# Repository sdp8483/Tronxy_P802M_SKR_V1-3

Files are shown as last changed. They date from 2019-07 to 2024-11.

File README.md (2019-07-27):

# Tronxy P802M with BIGTREETECH SKR V1.3 Controller - Marlin 2.0 Firmware Cofiguration Files

Upgrade guide for replacing stock Tronxy P802M controller: [samueldperry.com](https://samueldperry.com/2019/07/21/tronxy-p802m-controller-upgrade-to-32-bits/ "Upgrade Guide")

For stock hardware (other then the controller) use config files in *Stock Hardware* directory.

For 3D Touch Probe (BLTouch Clone)) use config files in *3D Touch* directory.

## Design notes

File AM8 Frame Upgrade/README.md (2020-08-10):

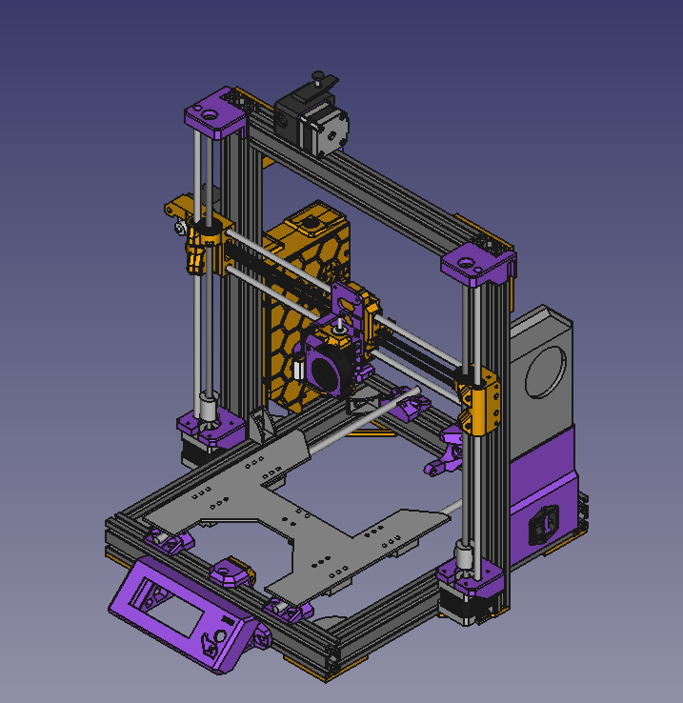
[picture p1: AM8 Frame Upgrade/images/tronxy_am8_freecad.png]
Tronxy AM8 FreeCAD Render


# Frame
[AM8 Frame](https://www.thingiverse.com/thing:2263216): use for aluminum cut dimensions and printed frame support parts.
Follow the [AM8 Build guide](https://www.thingiverse.com/download:3592429) but substitute the modified parts below for the original AM8 printed parts.

# Printed Parts
Parts are borrowed from the sources listed in the [Sources and Inspiration](#sources-and-inspiration) section.
The AM8 2040 extrusion profile is different from the Prusa Bear 2040 extrusion profile so parts that connect to the 2040 profiles have been modified.

Item Number | Item | Quantity | Notes
------------|------|----------|------
1  | [AM8 to corner plate](CAD/stl/2_Top_Corner_Plate.stl) | 2 | from [AM8 Frame](https://www.thingiverse.com/thing:2263216)
2  | [AM8 bottom tee plate](CAD/stl/2_Bottom_Tee_Plate.stl) | 2 | from [AM8 Frame](https://www.thingiverse.com/thing:2263216)
3  | [AM8 bottom corner plate](CAD/stl/4_Bottom_Corner_Plate.stl) | 4 | from [AM8 Frame](https://www.thingiverse.com/thing:2263216)
4  | [left z motor mount](CAD/stl/z_motor_mount_left.stl) | 1 | based on z motor mounts from full Prusa Bear Upgrade
5  | [right z motor mount](CAD/stl/z_motor_mount_right.stl) | 1 | based on z motor mounts from full Prusa Bear Upgrade
6  | [left z stabilizer](CAD/stl/z_stabilizer_left.stl) | 1 | holds z smooth rod and leadscrew, requires 608 bearing
7  | [right z stabilizer](CAD/stl/z_stabilizer_right.stl) | 1 | holds z smooth rod and leadscrew, requires 608 bearing
8  | [x motor mount](CAD/stl/x_end_motor.stl) | 1 | unmodifed from Prusa Bear Upgrade. Print the mk2.5s version if using limit switches. Either if using sensorless homing
9  | [x end idler](CAD/stl/x_end_idler.stl) | 1 | unmodifed from Prusa Bear Upgrade, cut x rods to 405mm long
10 | [x end idler tensioner](CAD/stl/x_end_idler_tensioner.stl) | 1 | unmodifed from Prusa Bear Upgrade.
11 | [y rod holder](CAD/stl/y_rod_holder.stl) | 4 | 
12 | [y motor mount](CAD/stl/y_motor_mount_modified.stl) | 1 | modified prusa bear part to fit extrusion profile
13 | [y idler bottom](CAD/stl/y_idler_bottom_modified.stl) | 1 | modified from Thingiverse thing:[3502543](https://www.thingiverse.com/thing:3502543) to fit extrusion profile
14 | [y idler holder](CAD/stl/y_idler_holder_Bear_RHD.stp) | 1 | unmodified from Thingiverse thing:[3502543](https://www.thingiverse.com/thing:3502543)
15 | [y belt holder](CAD/stl/y_belt_holder.stl) | 1 |
16 | [x carriage back](CAD/stl/x_carriage_back.stl) | 1 | unmodifed from Prusa Bear Upgrade.
17 | [x carriage](CAD/stl/x_carriage.stl) | 1 | unmodifed from Prusa Bear Upgrade.
18 | [hotend mount](CAD/stl/hotend_mount_modified.stl) | 1 | modified from Prusa Bear Upgrade for bowden setup
19 | [extruder cover](CAD/stl/extruder_cover.stl) | 1 | unmodified from Prusa Bear upgrade
20 | [cable guide back A](CAD/stl/cable_guide_back_a.stl) | 1 | unmodified from Prusa Bear upgrade
21 | [cable guide back B](CAD/stl/cable_guide_back_b.stl) | 1 | unmodified from Prusa Bear upgrade
22 | [lcd support a modified](CAD/stl/lcd_support_a_modified.stl) | 1 | modified prusa bear part to fit extrusion profile and for LCD contrast pot
23 | [lcd support b modified](CAD/stl/lcd_support_b_modified.stl) | 1 | modified prusa bear part to fit extrusion profile
24 | [lcd cover](CAD/stl/lcd_cover.stl) | 1 | modified from prusa
25 | [SKR V14 Body](CAD/stl/SKR_V14_Body.stl) | 1 | unmodified from Universal BTT SKR Box
26 | [SKR V14 Cover](CAD/stl/SKR_V14_Cover.stl) | 1 | unmodified from Universal BTT SKR Box
27 | [SKR Bear Long Anchor Modified](CAD/stl/Anchor_SKR_Bear_Long_modified.stl) | 1 | modified version of Universal BTT SKR mount, attaches enclosure to frame
28 | [Bear MK3 Body](CAD/stl/Bear_MK3_Body.stl) | 1 | unmodified from Universal BTT SKR Box
29 | [Bear MK3 Cover](CAD/stl/Bear_MK3_Cover.stl) | 1 | unmodified from Universal BTT SKR Box
30 | [BTT Bottom Mount](CAD/stl/BTT_mount_bottom.stl) | 1 | used to mount Universal BTT SKR Box to the bottom rail
31 | [PSU Top Bracket](CAD/stl/psu_bracket_top.stl) | 1 | bracket to mount top of power supply to frame
32 | [PSU Bottom Bracket](CAD/stl/psu_bracket_bottom.stl) | 1 | bracket to mount bottom of power supply to frame
33 | [PSU Cover](CAD/stl/psu_cover.stl) | 1 | cover and mount for bottom of power supply
34 | [BL Touch Fan Mount](CAD/stl/bl_mount_fan.stl) | 1 | mounts BL Touch to layer fan, first bracket
35 | [BL Touch Mount](CAD/stl/bl_touch_bracket.stl) | 1 | mounts BL touch to layer fan, second bracket
36 | [Extruder Mount](CAD/stl/extruder_mount.stl) | 1 | bowden mount for bondtech BMG (clone) extruder and pancake stepper

# Extra
I had issues with the Bondtech Clone extruder so scraped it and went with a genuine E3D Hemera. I followed the documentation found here: [bearmera](https://github.com/gregsaun/bear_extruder_and_x_axis/blob/master/optional_parts/bear_hemera/README.md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). Since I already had the bear x axis I only needed to print the Hemear specific mounts and nozzle.

# Sources and Inspiration

[AM8 Frame](https://www.thingiverse.com/thing:2263216)  
[Prusa Bear Upgrade](https://github.com/gregsaun/prusa_i3_bear_upgrade)  
[Prusa Bear Extruder and X Axis](https://github.com/gregsaun/bear_extruder_and_x_axis)  
[Y-belt tensioner and Y-belt holder for Bear upgrade MK3/MK3S](https://www.thingiverse.com/thing:3502543)  
[Universal BTT SKR V1.3 & v1.4 Box](https://www.thingiverse.com/thing:4178177)  
[Bear Ends and Raspberry Modules for Universal Boxes](https://www.thingiverse.com/thing:4210933)  
[LM8UU Bearing Block 3d Model](https://grabcad.com/library/lm8uu-bearing-block-1)  
[Power Supply 3d Model](https://grabcad.com/library/power-supply-s-240-12-1)  
[BL Touch 3d Model](https://grabcad.com/library/bl-touch-for-3d-printers-1)  
[Bondtech BMG 3d Model](https://www.bondtech.se/downloads/STEP/BMG_Extruder_RH_STEP.zip)  
[Pancake Stepper Motor](https://grabcad.com/library/e3d-slimline-stepper-motor-0-9-stepping-angle-1)  
[NEMA 17 Stepper](https://grabcad.com/library/nema-17-28-60mm-stepper-motor-1)

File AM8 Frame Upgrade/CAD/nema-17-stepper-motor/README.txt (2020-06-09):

https://grabcad.com/library/nema-17-28-60mm-stepper-motor-1

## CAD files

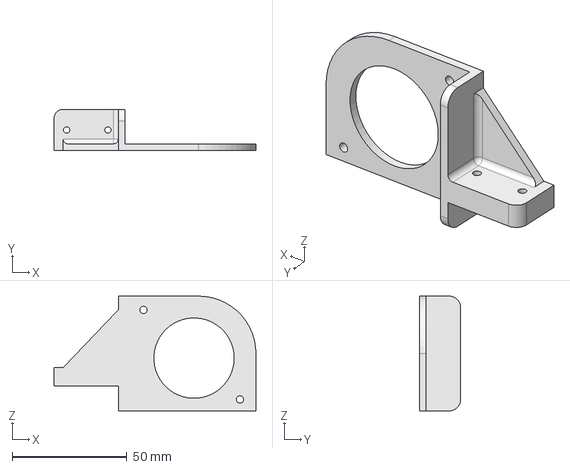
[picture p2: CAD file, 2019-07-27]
3D Touch/Tronxy_P802M_3DTouch_Mount.FCStd
88.0 x 18.0 x 50.0 mm

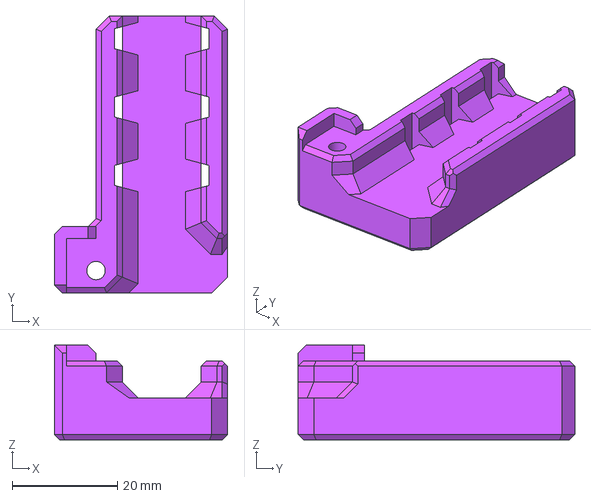
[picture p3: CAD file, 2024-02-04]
AM8 Frame Upgrade/CAD/heated_bed_mount.FCStd
32.9 x 52.7 x 18.0 mm

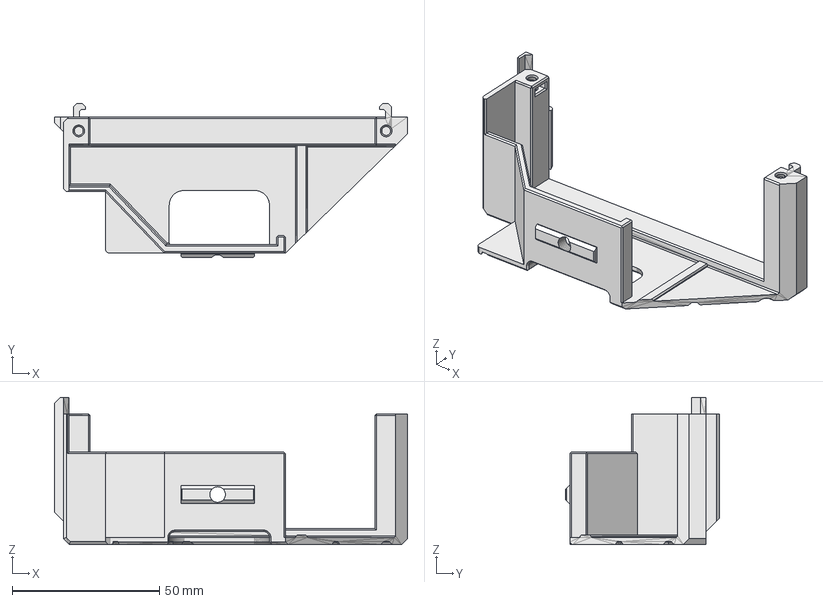
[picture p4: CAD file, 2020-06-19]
AM8 Frame Upgrade/CAD/mods/Bear_MK3_Body_modified.FCStd
120.0 x 52.2 x 50.0 mm

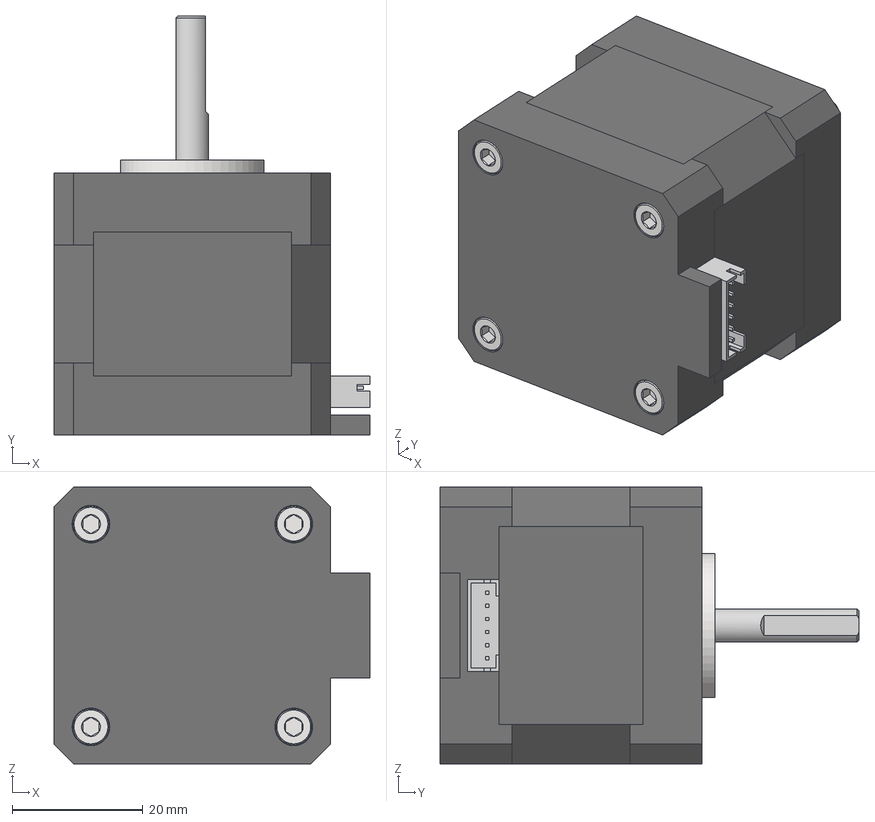
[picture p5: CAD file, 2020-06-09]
AM8 Frame Upgrade/CAD/nema-17-stepper-motor/Nema 17 40mm.step
48.3 x 64.0 x 42.3 mm
Mid
Shaft
Pin
Screw x 4

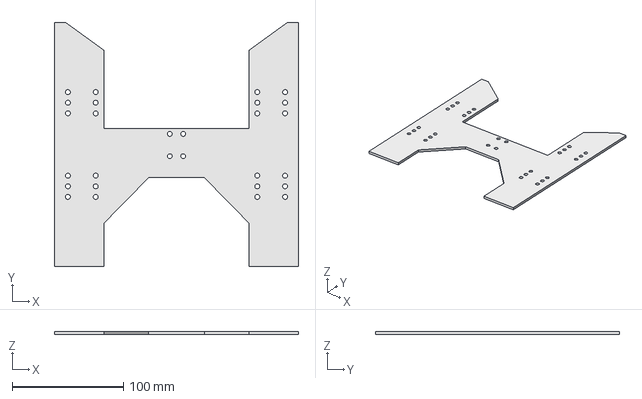
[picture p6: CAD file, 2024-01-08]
AM8 Frame Upgrade/CAD/step/bed_plate.step
219.0 x 219.0 x 3.00 mm

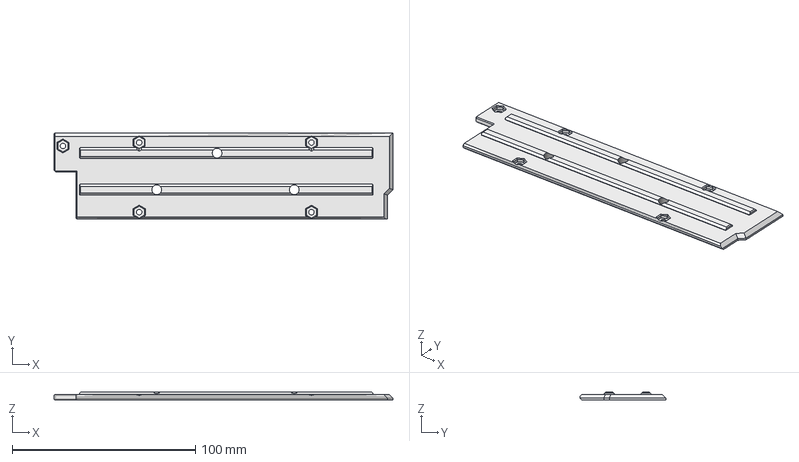
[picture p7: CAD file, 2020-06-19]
AM8 Frame Upgrade/CAD/mods/Anchor_SKR_Bear_Long_modified.FCStd
185.0 x 47.0 x 4.40 mm

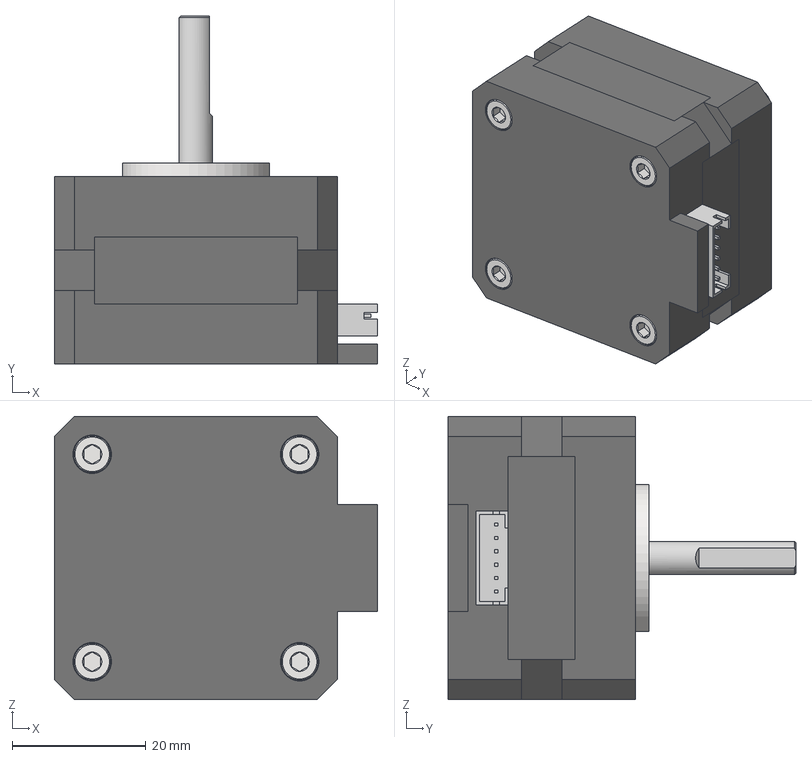
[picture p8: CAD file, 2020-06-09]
AM8 Frame Upgrade/CAD/nema-17-stepper-motor/Nema 17 28mm.step
48.3 x 52.0 x 42.3 mm
Mid
Shaft
Pin
Screw x 4

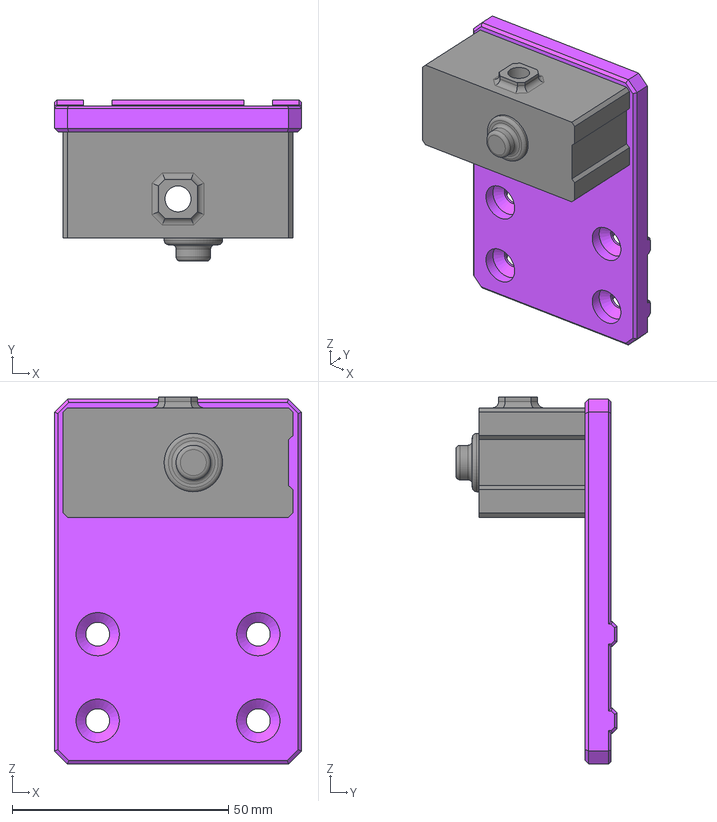
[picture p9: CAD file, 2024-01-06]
AM8 Frame Upgrade/CAD/sfs_v2.FCStd
57.1 x 37.3 x 84.8 mm
sfs_v2.0
mount

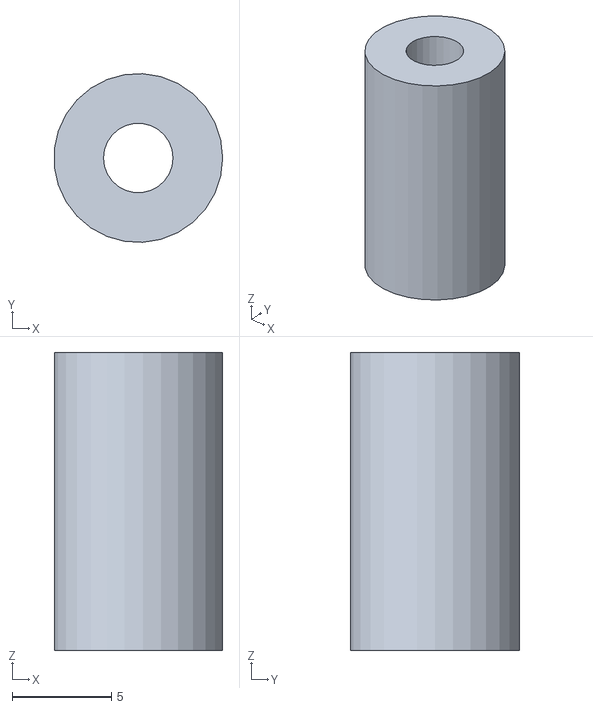
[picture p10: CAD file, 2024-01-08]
AM8 Frame Upgrade/CAD/stl/bed_standoff.stl
8.48 x 8.49 x 15.0

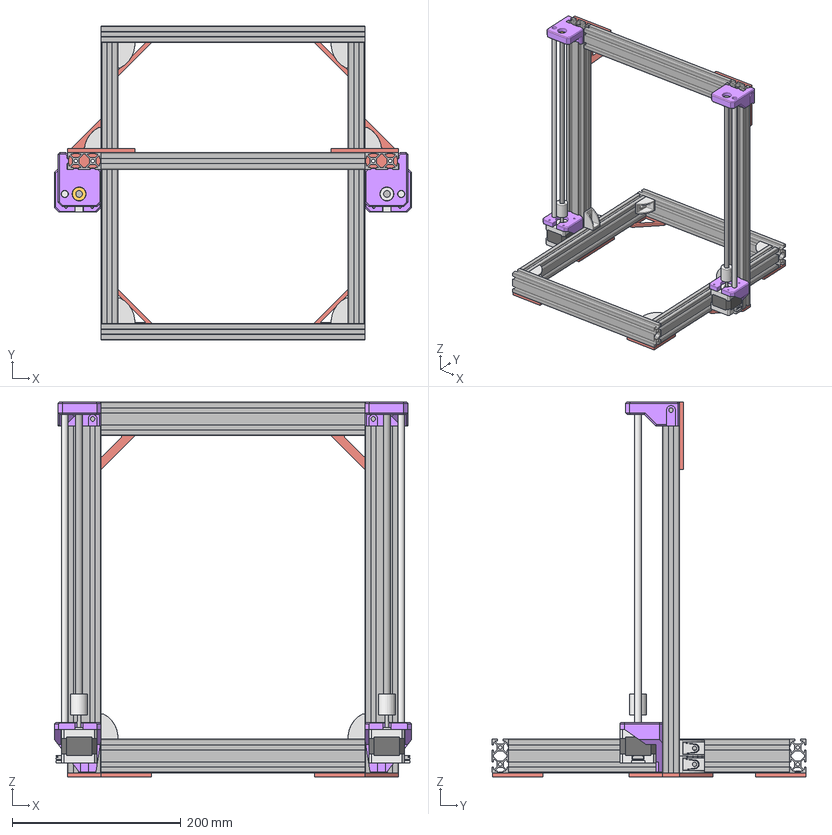
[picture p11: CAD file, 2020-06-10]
AM8 Frame Upgrade/CAD/AM8-pbear.FCStd
424.0 x 373.0 x 445.0 mm
Vertical
Vertical001
Bottom Horizontal 313
Bottom Horizontal 314
Bottom Right
Bottom Right001
Topper 313
2040x2040 Slotted
2040x2040 Slotted001
Bottom Tee
Bottom Tee001
Corner2020
Corner2021
Corner2022
Corner2023
_HBLFSNF5_b
_HBLFSNF5_b001
_HBLFSNF5_b002
_HBLFSNF5_b003
_HBLFSNF5_b004
_HBLFSNF5_b005
_HBLFSNF5_b006
_HBLFSNF5_b007
_HBLFSNF5_b008
_HBLFSNF5_b009
Mid
Shaft
Pin
Mid001
Shaft001
Pin001
z coupler left
z coupler right
leadscrew left
leadscrew right
zrod left
zrod right
z_motor_mount_left
z_motor_mount_right
608 left
608 right
z_stabalizer_left
z_stabalizer_right

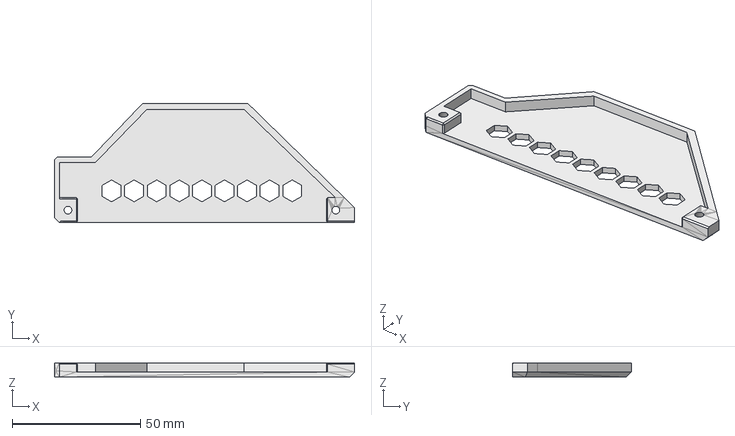
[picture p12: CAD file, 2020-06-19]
AM8 Frame Upgrade/CAD/step/Bear_Mk3_Cover.step
117.0 x 46.3 x 5.60 mm

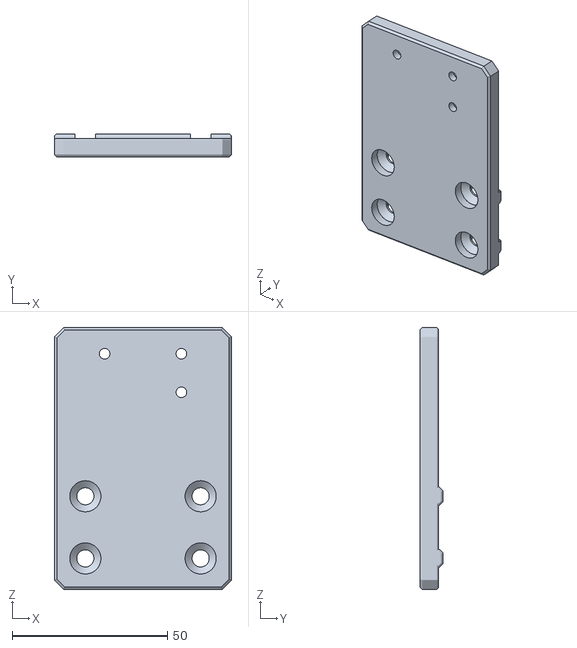
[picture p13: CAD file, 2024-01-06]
AM8 Frame Upgrade/CAD/stl/sfs_v2-mount.stl
57.1 x 7.40 x 84.3

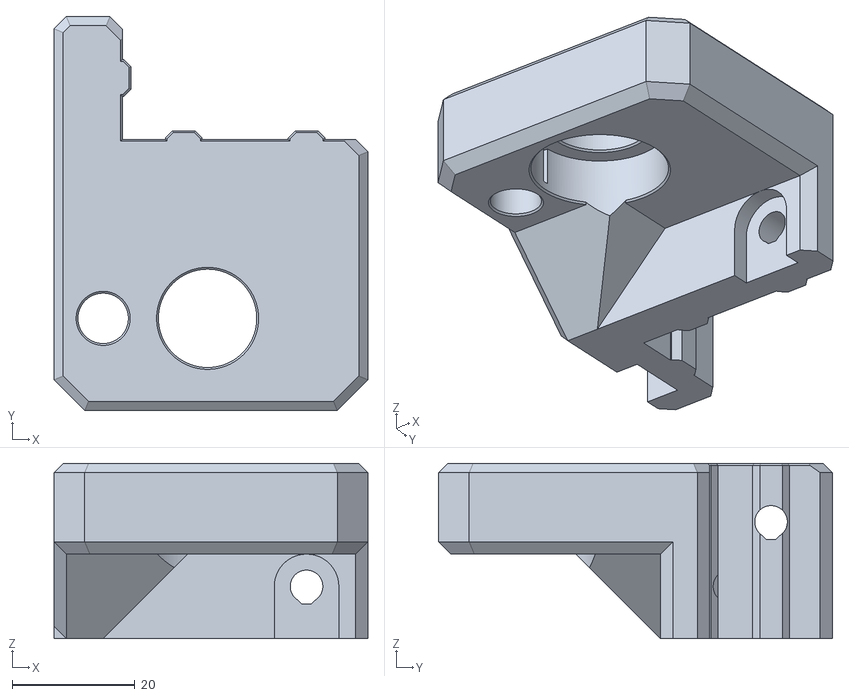
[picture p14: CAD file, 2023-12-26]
AM8 Frame Upgrade/CAD/stl/z_stabilizer_left.stl
51.1 x 64.1 x 28.5

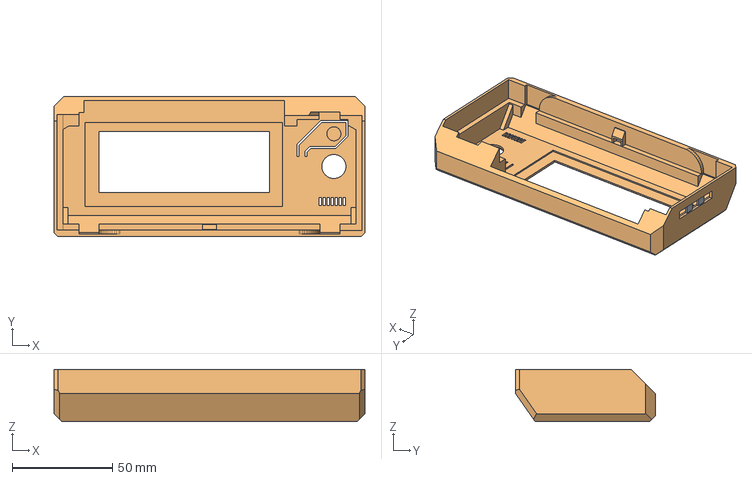
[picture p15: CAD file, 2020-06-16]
AM8 Frame Upgrade/CAD/step/lcd_cover.step
155.0 x 70.0 x 26.0 mm

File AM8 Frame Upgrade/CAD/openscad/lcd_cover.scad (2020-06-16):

// PRUSA iteration4
// LCD cover
// GNU GPL v3
// Josef Průša <iam@josefprusa.cz> and contributors
// http://www.reprap.org/wiki/Prusa_Mendel
// http://prusamendel.org


module main_body()
{
    difference() 
    {
        union() 
        {
            // main body
            translate( [ -77 , -4.5 , 0 ] ) cube( [ 155 , 59.8 , 2 ] ); 
            translate( [ -77 , -4.5 , 0 ] ) rotate([35,0,0]) cube( [ 155 , 2 , 20.08 ] );
            translate( [ -77 , -3.5 , -1 ] ) rotate([35,0,0]) cube( [ 7 , 5 , 15 ] );
            translate( [ 71 , -3.5 , -1 ] ) rotate([35,0,0]) cube( [ 7 , 5 , 15 ] );
            translate( [ -77 , -14.7 , 14.2 ] )  cube( [ 155 , 2 , 11.8 ] );
            translate( [ -77 , 54 , 0 ] ) cube( [ 155 , 2 , 17 ] );
            
            // M3 hole body
            translate( [ 73.5 , 43.3 , 0.5 ] ) rotate([0,0,90])  cylinder( h = 14, r = 4, $fn=6);  
            translate( [ -72.5 , 43.5 , 0.5 ] ) rotate([0,0,90])  cylinder( h = 14, r = 4, $fn=6);  
        }
        
        // LCD window
        translate( [ -61.5 , 1 , 1.2 ] ) cube( [ 98.5 , 42 , 10 ] ); 
        translate( [ -54.5 , 8 , -1 ] ) cube( [ 85 , 30.5 , 10 ] );  

        // buzzer holes
        translate( [ 55 , 1.5 , -1 ] ) cube( [ 1.3 , 4 , 10 ] );  
        translate( [ 57 , 1.5 , -1 ] ) cube( [ 1.3 , 4 , 10 ] );  
        translate( [ 59 , 1.5 , -1 ] ) cube( [ 1.3 , 4 , 10 ] );  
        translate( [ 61 , 1.5 , -1 ] ) cube( [ 1.3 , 4 , 10 ] );  
        translate( [ 63 , 1.5 , -1 ] ) cube( [ 1.3 , 4 , 10 ] );  
        translate( [ 65 , 1.5 , -1 ] ) cube( [ 1.3 , 4 , 10 ] );  
        translate( [ 67 , 1.5 , -1 ] ) cube( [ 1.3 , 4 , 10 ] );  

        // buzzer holes corners
        translate( [ 66.25 , 1.5 , -0.5 ] ) rotate([0,45,0]) cube( [ 2 , 4 , 2 ] );  
        translate( [ 64.25 , 1.5 , -0.5 ] ) rotate([0,45,0]) cube( [ 2 , 4 , 2 ] );  
        translate( [ 62.25 , 1.5 , -0.5 ] ) rotate([0,45,0]) cube( [ 2 , 4 , 2 ] );  
        translate( [ 60.25 , 1.5 , -0.5 ] ) rotate([0,45,0]) cube( [ 2 , 4 , 2 ] );  
        translate( [ 58.25 , 1.5 , -0.5 ] ) rotate([0,45,0]) cube( [ 2 , 4 , 2 ] );  
        translate( [ 56.25 , 1.5 , -0.5 ] ) rotate([0,45,0]) cube( [ 2 , 4 , 2 ] );  
        translate( [ 54.25 , 1.5 , -0.5 ] ) rotate([0,45,0]) cube( [ 2 , 4 , 2 ] );  

        // knob hole
        translate( [ 62.5 , 21 , -1 ] ) cylinder( h = 10, r = 6, $fn=30);
        translate( [ 62.5 , 21 , -1.2 ] ) cylinder( h = 2, r1 = 7, r2 = 6, $fn=30);

        // reset button cutout
        translate( [ 44 , 26 , -1 ] ) cube( [ 1 , 6 , 9 ] );  
        translate( [ 48 , 26 , -1 ] ) cube( [ 1 , 2.5 , 9 ] );  
        translate( [ 68.5 , 36 , -1 ] ) cube( [ 1 , 8 , 9 ] );  
        translate( [ 56 , 43 , -1 ] ) cube( [ 13.5 , 1 , 9 ] ); 
        translate( [ 50.5 , 30 , -1 ] ) cube( [ 13 , 1 , 9 ] ); 
        translate( [ 44.7 , 31.28 , -1 ] ) rotate([0,0,45]) cube( [ 17 , 1 , 9 ] );  
        translate( [ 63.5 , 30 , -1 ] ) rotate([0,0,45]) cube( [ 8.5 , 1 , 9 ] );  
        translate( [ 48.7 , 27.8 , -1 ] ) rotate([0,0,45]) cube( [ 3.55 , 1 , 9 ] );

        // rear support cutout
        translate( [ -64.5 , -12.7 , 14 ] ) cube( [ 10 , 3 , 16 ] );  
        translate( [ 55.5 , -12.7 , 14 ] ) cube( [ 10 , 3 , 16 ] );  

    }
}

module pcb_clip()
{
    difference()
    {
    union()
        {
            translate( [ -3 , -12 , 17.5 ] ) cube( [ 7 , 4 , 5 ] ); 
            translate( [ -3 , -10.6 , 12.5 ] ) cube( [ 1 , 2.6 , 7 ] );  
            translate( [ 3 , -10.6 , 12.5 ] ) cube( [ 1 , 2.6 , 7 ] );  
        }
        translate( [ -4 , -8 , 18.5 ] ) rotate([30,0,0]) cube( [ 10 , 6 , 6 ] );  
        translate( [ 2.5 , -12 , 14.5 ] ) cube( [ 1 , 4 , 0.2 ] );  
        translate( [ -2.5 , -12 , 14.5 ] ) cube( [ 1 , 4 , 0.2 ] );  
        translate( [ 2.5 , -12 , 17.3 ] ) cube( [ 1 , 4 , 0.2 ] );  
        translate( [ -2.5 , -12 , 17.3 ] ) cube( [ 1 , 4 , 0.2 ] );          
    }
}



difference()
{
    union()
    {

    pcb_clip();
    main_body();

    // reset button
    translate( [ 62.5 , 37.3 , 0 ] ) cylinder( h = 7.2, r = 3.5, $fn=30); 

    //left side
    translate( [ -77 , -14.7 , 0 ] ) cube( [ 1.5 , 70.7 , 26 ] );  
    translate( [ -76.5 , -15 , 0 ] ) cube( [ 4 , 70 , 14.6 ] );  

    //right side
    translate( [ 76.5 , -14.7 , 0 ] ) cube( [ 1.5 , 70.7 , 26 ] ); 
    translate( [ 73.5 , -14 , 0 ] ) cube( [ 4 , 70 , 14.5 ] );  

    //rear side reinforcement
    translate( [ -54.5 , -11.7 , 8 ] ) cube( [ 110 , 4 , 6.5 ] );  
    translate( [ 65.5 , -11.7 , 8 ] ) cube( [ 12 , 4 , 6.5 ] );  
    translate( [ 65.5 , -13 , 14 ] ) cube( [ 12 , 2 , 12 ] );  
    translate( [ -76.5 , -11.7 , 8 ] ) cube( [ 12 , 4 , 6.5 ] );  
    translate( [ -76.5 , -14.7 , 14.5 ] ) cube( [ 12 , 4 , 11.5 ] );  
    translate( [ -44 , -14.7 , 14.5 ] ) cube( [ 89 , 4 , 11.5 ] );  
    translate( [ -43.5 , -10.7 , 15 ] ) rotate([90,0,0]) cylinder( h = 2, r = 11, $fn=60);  
    translate( [ 44.5 , -10.7 , 15 ] ) rotate([90,0,0]) cylinder( h = 2, r = 11, $fn=60);  

    //front left side reinforcement
    difference()
    {
        union()
            {
                translate( [ -77 , 41.3 , 0 ] ) cube( [ 15 , 14 , 25 ] );  
                translate( [ -77 , 46.3 , 14 ] ) cube( [ 15 , 9 , 3 ] );    
            }
        translate( [ -64.5 , 40 , -3 ] ) cube( [ 4 , 8 , 40 ] );  
        translate( [ -75.5 , 40.3 , 14.5 ] ) cube( [15 , 6.5 , 25 ] ); 
    }


    //front right side reinforcement
    difference()
        {
            translate( [ 38 , 41.2 , 0 ] ) cube( [ 40 , 14 , 26 ] );  
            translate( [ 55 , 44.5 , 0 ] ) cube( [ 10.5 , 3.7 , 30 ] );  
            translate( [ 44 , 39.5 , 0 ] ) cube( [ 25.5 , 5 , 30 ] );  
            translate( [ 35 , 39.3 , 14.5 ] ) cube( [ 42.5 , 7 , 15 ] );  
            translate( [ 49 , 43.2 , 25 ] ) rotate([0,60,0]) cube( [ 12 , 5 , 10 ] );  
        }
    }

    // SD card opening
    translate( [ -80 , 9 , 16.5 ] ) cube( [ 10 , 28 , 4.5 ] );  

    // front and rear angle
    translate( [ -81 , -9.3 , -17 ] ) rotate([35,0,0]) cube( [ 164 , 14 , 54.08 ] );  
    translate( [ -78 , 72.7 , -3 ] ) rotate([45,0,0]) cube( [ 160 , 14 , 54.08 ] );  

    // M3 screw thread
    translate( [ 72.5 , 43.2 , 3 ] ) cylinder( h = 20, r = 1.4, $fn=30);  
    translate( [ -72.5 , 42.7 , 3 ] ) cylinder( h = 20, r = 1.4, $fn=30); 
    translate( [ 72.5 , 43.2 , 11.7 ] ) cylinder( h = 3, r1 = 1.4, r2=2.2, $fn=30);  
    translate( [ -72.5 , 42.7 , 11.7 ] ) cylinder( h = 3, r1 = 1.4, r2=2.2, $fn=30);  

    // front cleanup
    translate( [ -100 , -64 , 0 ] ) cube( [ 200 , 50 , 50 ] ); 

    // X sign on reset button
    translate( [ 63 , 34 , -1 ] ) rotate([0,0,45]) cube( [ 2, 8, 2 ] );  
    translate( [ 57.5 , 35.5 , -1 ] ) rotate([0,0,-45]) cube( [ 2, 8, 2 ] );  

    // corners
    translate( [ 73 , -5 , -1 ] ) rotate([0,45,0]) cube( [ 7, 80, 7 ] );  
    translate( [ -82 , -5 , -1 ] ) rotate([0,45,0]) cube( [ 7, 80, 7 ] );  

    translate( [ -82 , 58 , -5 ] ) rotate([45,0,0]) cube( [ 200, 7, 7 ] );  
    translate( [ -77 , 51 , -4 ] ) rotate([0,0,45]) cube( [ 8, 8, 50 ] );  
    translate( [ 78 , 51 , -4 ] ) rotate([0,0,45]) cube( [ 8, 8, 50 ] );  
    translate( [ 78 , -19 , -4 ] ) rotate([0,0,45]) cube( [ 5, 5, 50 ] );  
    translate( [ -77 , -19 , -4 ] ) rotate([0,0,45]) cube( [ 5, 5, 50 ] );  

    // LCD corners
    translate( [ -54.5 , 9.5 , -5.2 ] ) rotate([45,0,0]) cube( [ 85 , 5 , 5 ] );  // LCD window
    translate( [ -54.5 , 37 , -5.2 ] ) rotate([45,0,0]) cube( [ 85 , 5 , 5 ] );  // LCD window
    rotate([35,0,0]) translate( [ -78 , -8 , -4 ] ) rotate([0,0,45]) cube( [ 6, 6, 50 ] );  
    rotate([35,0,0]) translate( [ 79 , -8 , -4 ] ) rotate([0,0,45]) cube( [ 6, 6, 50 ] );  
    translate( [ -100 , -40 , -50 ] ) cube( [ 200 , 50 , 50 ] );     
    
}

// print support for SD card opening
translate( [ -76.5 , 15 , 16.70 ] ) cube( [ 1 , 5 , 4.1 ] );
translate( [ -76.5 , 25 , 16.70 ] ) cube( [ 1 , 5 , 4.1 ] );

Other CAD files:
AM8 Frame Upgrade/CAD/stl/bed_standoff_wire_strain_relief.stl
AM8 Frame Upgrade/CAD/step/Bear_MK3_Body_modified.step
AM8 Frame Upgrade/CAD/step/Anchor_SKR_Bear_Long_modified.step
AM8 Frame Upgrade/CAD/stl/z_stabilizer_right.stl
3D Touch/Tronxy_P802M_3DTouch_Mount.stl
AM8 Frame Upgrade/CAD/step/AM8.step
AM8 Frame Upgrade/CAD/step/Y_idler_bottom_Bear_RHD.stp
AM8 Frame Upgrade/CAD/step/y_idler.step
AM8 Frame Upgrade/CAD/step/y_motor_mount.step
AM8 Frame Upgrade/CAD/step/z_motor_mount_left.step
AM8 Frame Upgrade/CAD/step/z_stabalizer_left.step
AM8 Frame Upgrade/CAD/stl/2_Bottom_Tee_Plate.stl
AM8 Frame Upgrade/CAD/stl/2_Top_Corner_Plate.stl
AM8 Frame Upgrade/CAD/stl/4_Bottom_Corner_Plate.stl
AM8 Frame Upgrade/CAD/stl/Anchor_SKR_Bear_Long_modified.stl
AM8 Frame Upgrade/CAD/stl/BTT_mount_bottom.stl
AM8 Frame Upgrade/CAD/stl/Bear_MK3_Body.stl
AM8 Frame Upgrade/CAD/stl/Bear_MK3_Cover.stl
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

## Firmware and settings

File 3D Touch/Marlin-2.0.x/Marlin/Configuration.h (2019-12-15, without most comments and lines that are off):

#pragma once
#define CONFIGURATION_H_VERSION 020000
#define STRING_CONFIG_H_AUTHOR "(Sam Perry)" // Who made the changes.
#define SHOW_BOOTSCREEN
#define SERIAL_PORT -1
#define SERIAL_PORT_2 0
#define BAUDRATE 115200
  #define MOTHERBOARD BOARD_BIGTREE_SKR_V1_3
#define EXTRUDERS 1
#define DEFAULT_NOMINAL_FILAMENT_DIA 1.75
#define TEMP_SENSOR_0 1
#define TEMP_SENSOR_1 0
#define TEMP_SENSOR_2 0
#define TEMP_SENSOR_3 0
#define TEMP_SENSOR_4 0
#define TEMP_SENSOR_5 0
#define TEMP_SENSOR_BED 1
#define TEMP_SENSOR_CHAMBER 0
#define DUMMY_THERMISTOR_998_VALUE 25
#define DUMMY_THERMISTOR_999_VALUE 100
#define MAX_REDUNDANT_TEMP_SENSOR_DIFF 10
#define TEMP_RESIDENCY_TIME     10  // (seconds) Time to wait for hotend to "settle" in M109
#define TEMP_WINDOW              1  // (°C) Temperature proximity for the "temperature reached" timer
#define TEMP_HYSTERESIS          3  // (°C) Temperature proximity considered "close enough" to the target
#define TEMP_BED_RESIDENCY_TIME 10  // (seconds) Time to wait for bed to "settle" in M190
#define TEMP_BED_WINDOW          1  // (°C) Temperature proximity for the "temperature reached" timer
#define TEMP_BED_HYSTERESIS      3  // (°C) Temperature proximity considered "close enough" to the target
#define HEATER_0_MINTEMP   5
#define HEATER_1_MINTEMP   5
#define HEATER_2_MINTEMP   5
#define HEATER_3_MINTEMP   5
#define HEATER_4_MINTEMP   5
#define HEATER_5_MINTEMP   5
#define BED_MINTEMP        5
#define HEATER_0_MAXTEMP 275
#define HEATER_1_MAXTEMP 275
#define HEATER_2_MAXTEMP 275
#define HEATER_3_MAXTEMP 275
#define HEATER_4_MAXTEMP 275
#define HEATER_5_MAXTEMP 275
#define BED_MAXTEMP      150
#define PIDTEMP
#define BANG_MAX 250     // Limits current to nozzle while in bang-bang mode; 255=full current
#define PID_MAX BANG_MAX // Limits current to nozzle while PID is active (see PID_FUNCTIONAL_RANGE below); 255=full current
#define PID_K1 0.95      // Smoothing factor within any PID loop
  #define PID_FUNCTIONAL_RANGE 10 // If the temperature difference between the target temperature and the actual temperature
  #define DEFAULT_Kp 22.2
  #define DEFAULT_Ki 1.08
  #define DEFAULT_Kd 114
#define MAX_BED_POWER 255 // limits duty cycle to bed; 255=full current
#define PREVENT_COLD_EXTRUSION
#define EXTRUDE_MINTEMP 170
#define PREVENT_LENGTHY_EXTRUDE
#define EXTRUDE_MAXLENGTH 200
#define THERMAL_PROTECTION_HOTENDS // Enable thermal protection for all extruders
#define THERMAL_PROTECTION_BED     // Enable thermal protection for the heated bed
#define USE_XMIN_PLUG
#define USE_YMIN_PLUG
#define USE_ZMIN_PLUG
#define ENDSTOPPULLUPS
#define X_MIN_ENDSTOP_INVERTING true // Set to true to invert the logic of the endstop.
#define Y_MIN_ENDSTOP_INVERTING true // Set to true to invert the logic of the endstop.
#define Z_MIN_ENDSTOP_INVERTING true // Set to true to invert the logic of the endstop.
#define X_MAX_ENDSTOP_INVERTING false // Set to true to invert the logic of the endstop.
#define Y_MAX_ENDSTOP_INVERTING false // Set to true to invert the logic of the endstop.
#define Z_MAX_ENDSTOP_INVERTING false // Set to true to invert the logic of the endstop.
#define Z_MIN_PROBE_ENDSTOP_INVERTING false // Set to true to invert the logic of the probe.
#define X_DRIVER_TYPE  A4988
#define Y_DRIVER_TYPE  A4988
#define Z_DRIVER_TYPE  A4988
#define E0_DRIVER_TYPE A4988
#define DEFAULT_AXIS_STEPS_PER_UNIT   { 100, 100, 400, 90 }
#define DEFAULT_MAX_FEEDRATE          { 300, 300, 5, 25 }
#define LIMITED_MAX_FR_EDITING        // Limit edit via M203 or LCD to DEFAULT_MAX_FEEDRATE * 2
  #define MAX_FEEDRATE_EDIT_VALUES    { 600, 600, 10, 50 } // ...or, set your own edit limits
#define DEFAULT_MAX_ACCELERATION      { 3000, 3000, 100, 10000 }
#define LIMITED_MAX_ACCEL_EDITING     // Limit edit via M201 or LCD to DEFAULT_MAX_ACCELERATION * 2
  #define MAX_ACCEL_EDIT_VALUES       { 6000, 6000, 200, 20000 } // ...or, set your own edit limits
#define DEFAULT_ACCELERATION          3000    // X, Y, Z and E acceleration for printing moves
#define DEFAULT_RETRACT_ACCELERATION  3000    // E acceleration for retracts
#define DEFAULT_TRAVEL_ACCELERATION   3000    // X, Y, Z acceleration for travel (non printing) moves
#define DEFAULT_EJERK    5.0  // May be used by Linear Advance
  #define JUNCTION_DEVIATION_MM 0.013 // (mm) Distance from real junction edge
#define Z_MIN_PROBE_USES_Z_MIN_ENDSTOP_PIN
#define BLTOUCH
#define NOZZLE_TO_PROBE_OFFSET { -26, -45, 0 }
#define MIN_PROBE_EDGE 3
#define XY_PROBE_SPEED 35*60
#define Z_PROBE_SPEED_FAST HOMING_FEEDRATE_Z
#define Z_PROBE_SPEED_SLOW (Z_PROBE_SPEED_FAST / 2)
#define MULTIPLE_PROBING 2
#define Z_CLEARANCE_DEPLOY_PROBE   10 // Z Clearance for Deploy/Stow
#define Z_CLEARANCE_BETWEEN_PROBES  5 // Z Clearance between probe points
#define Z_CLEARANCE_MULTI_PROBE     5 // Z Clearance between multiple probes
#define Z_AFTER_PROBING            10 // Z position after probing is done
#define Z_PROBE_LOW_POINT          -1 // Farthest distance below the trigger-point to go before stopping
#define Z_PROBE_OFFSET_RANGE_MIN -20
#define Z_PROBE_OFFSET_RANGE_MAX 20
#define Z_MIN_PROBE_REPEATABILITY_TEST
#define X_ENABLE_ON 0
#define Y_ENABLE_ON 0
#define Z_ENABLE_ON 0
#define E_ENABLE_ON 0 // For all extruders
#define DISABLE_X false
#define DISABLE_Y false
#define DISABLE_Z false
#define DISABLE_E false             // For all extruders
#define DISABLE_INACTIVE_EXTRUDER   // Keep only the active extruder enabled
#define INVERT_X_DIR false
#define INVERT_Y_DIR false
#define INVERT_Z_DIR true
#define INVERT_E0_DIR false
#define INVERT_E1_DIR false
#define INVERT_E2_DIR false
#define INVERT_E3_DIR false
#define INVERT_E4_DIR false
#define INVERT_E5_DIR false
#define X_HOME_DIR -1
#define Y_HOME_DIR -1
#define Z_HOME_DIR -1
#define X_BED_SIZE 220
#define Y_BED_SIZE 220
#define X_MIN_POS -40
#define Y_MIN_POS -5
#define Z_MIN_POS 0
#define X_MAX_POS 225
#define Y_MAX_POS 225
#define Z_MAX_POS 230
#define MIN_SOFTWARE_ENDSTOPS
  #define MIN_SOFTWARE_ENDSTOP_X
  #define MIN_SOFTWARE_ENDSTOP_Y
  #define MIN_SOFTWARE_ENDSTOP_Z
#define MAX_SOFTWARE_ENDSTOPS
  #define MAX_SOFTWARE_ENDSTOP_X
  #define MAX_SOFTWARE_ENDSTOP_Y
  #define MAX_SOFTWARE_ENDSTOP_Z
  #define SOFT_ENDSTOPS_MENU_ITEM  // Enable/Disable software endstops from the LCD
#define AUTO_BED_LEVELING_BILINEAR
#define RESTORE_LEVELING_AFTER_G28
  #define ENABLE_LEVELING_FADE_HEIGHT
  #define SEGMENT_LEVELED_MOVES
  #define LEVELED_SEGMENT_LENGTH 5.0 // (mm) Length of all segments (except the last one)
  #define GRID_MAX_POINTS_X 5
  #define GRID_MAX_POINTS_Y GRID_MAX_POINTS_X
#define Z_SAFE_HOMING
  #define Z_SAFE_HOMING_X_POINT ((X_BED_SIZE) / 2)    // X point for Z homing when homing all axes (G28).
  #define Z_SAFE_HOMING_Y_POINT ((Y_BED_SIZE) / 2)    // Y point for Z homing when homing all axes (G28).
#define HOMING_FEEDRATE_XY (40*60)
#define HOMING_FEEDRATE_Z  (4*60)
#define VALIDATE_HOMING_ENDSTOPS
#define EEPROM_SETTINGS     // Persistent storage with M500 and M501
#define EEPROM_CHITCHAT       // Give feedback on EEPROM commands. Disable to save PROGMEM.
#define HOST_KEEPALIVE_FEATURE        // Disable this if your host doesn't like keepalive messages
#define DEFAULT_KEEPALIVE_INTERVAL 2  // Number of seconds between "busy" messages. Set with M113.
#define BUSY_WHILE_HEATING            // Some hosts require "busy" messages even during heating
#define PREHEAT_1_LABEL       "PLA"
#define PREHEAT_1_TEMP_HOTEND 210
#define PREHEAT_1_TEMP_BED     60
#define PREHEAT_1_FAN_SPEED     0 // Value from 0 to 255
#define PREHEAT_2_LABEL       "PETG"
#define PREHEAT_2_TEMP_HOTEND 235
#define PREHEAT_2_TEMP_BED     85
#define PREHEAT_2_FAN_SPEED     0 // Value from 0 to 255
#define NOZZLE_PARK_FEATURE
  #define NOZZLE_PARK_POINT { (X_MIN_POS + 10), (Y_MAX_POS - 10), 20 }
  #define NOZZLE_PARK_XY_FEEDRATE 40   // (mm/s) X and Y axes feedrate (also used for delta Z axis)
  #define NOZZLE_PARK_Z_FEEDRATE 5      // (mm/s) Z axis feedrate (not used for delta printers)
#define PRINTJOB_TIMER_AUTOSTART
#define PRINTCOUNTER
#define LCD_LANGUAGE en
#define DISPLAY_CHARSET_HD44780 WESTERN
#define LCD_INFO_SCREEN_STYLE 1
#define SDSUPPORT
#define REVERSE_ENCODER_DIRECTION
#define INDIVIDUAL_AXIS_HOMING_MENU
#define LCD_FEEDBACK_FREQUENCY_DURATION_MS 50
#define LCD_FEEDBACK_FREQUENCY_HZ 2000
#define REPRAP_DISCOUNT_SMART_CONTROLLER
#define SOFT_PWM_SCALE 0
#define SERVO_DELAY { 300 }

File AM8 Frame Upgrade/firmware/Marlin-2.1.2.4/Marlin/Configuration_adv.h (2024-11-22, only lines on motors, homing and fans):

#define E0_AUTO_FAN_PIN P2_04
#define E1_AUTO_FAN_PIN -1
#define E2_AUTO_FAN_PIN -1
#define E3_AUTO_FAN_PIN -1
#define E4_AUTO_FAN_PIN -1
#define E5_AUTO_FAN_PIN -1
#define E6_AUTO_FAN_PIN -1
#define E7_AUTO_FAN_PIN -1
#define CHAMBER_AUTO_FAN_PIN -1
#define COOLER_AUTO_FAN_PIN -1
#define HOMING_BUMP_MM      { 0, 0, 0 }       // (linear=mm, rotational=°) Backoff from endstops after first bump
#define HOMING_BUMP_DIVISOR { 2, 2, 4 }       // Re-Bump Speed Divisor (Divides the Homing Feedrate)
#define MICROSTEP_MODES { 16, 16, 16, 16, 16, 16 } // [1,2,4,8,16]
#define ADVANCED_PAUSE_FEATURE
  #define ADVANCED_PAUSE_PURGE_FEEDRATE        3  // (mm/s) Extrude feedrate (after loading). Should be slower than load feedrate.
  #define ADVANCED_PAUSE_PURGE_LENGTH         50  // (mm) Length to extrude after loading.
  #define ADVANCED_PAUSE_RESUME_PRIME          0  // (mm) Extra distance to prime nozzle after returning from park.
    #define X_CURRENT       800        // (mA) RMS current. Multiply by 1.414 for peak current.
    #define X_CURRENT_HOME  X_CURRENT  // (mA) RMS current for sensorless homing
    #define X_MICROSTEPS     16        // 0..256
    #define Y_CURRENT       800
    #define Y_CURRENT_HOME  Y_CURRENT
    #define Y_MICROSTEPS     16
    #define Z_CURRENT       800
    #define Z_CURRENT_HOME  Z_CURRENT
    #define Z_MICROSTEPS     16
    #define Z2_CURRENT      Z_CURRENT
    #define Z2_CURRENT_HOME Z_CURRENT_HOME
    #define Z2_MICROSTEPS   Z_MICROSTEPS
    #define CURRENT_STEP_DOWN     50  // [mA]
    #define REPORT_CURRENT_CHANGE
  #define X_HYBRID_THRESHOLD     100  // [mm/s]
  #define X2_HYBRID_THRESHOLD    100
  #define Y_HYBRID_THRESHOLD     100
  #define Y2_HYBRID_THRESHOLD    100
  #define Z_HYBRID_THRESHOLD       3
  #define Z2_HYBRID_THRESHOLD      3
  #define Z3_HYBRID_THRESHOLD      3
  #define Z4_HYBRID_THRESHOLD      3
  #define I_HYBRID_THRESHOLD       3  // [linear=mm/s, rotational=°/s]
  #define J_HYBRID_THRESHOLD       3  // [linear=mm/s, rotational=°/s]
  #define K_HYBRID_THRESHOLD       3  // [linear=mm/s, rotational=°/s]
  #define U_HYBRID_THRESHOLD       3  // [mm/s]
  #define V_HYBRID_THRESHOLD       3
  #define W_HYBRID_THRESHOLD       3
  #define E0_HYBRID_THRESHOLD     30
  #define E1_HYBRID_THRESHOLD     30
  #define E2_HYBRID_THRESHOLD     30
  #define E3_HYBRID_THRESHOLD     30
  #define E4_HYBRID_THRESHOLD     30
  #define E5_HYBRID_THRESHOLD     30
  #define E6_HYBRID_THRESHOLD     30
  #define E7_HYBRID_THRESHOLD     30
  #define SENSORLESS_HOMING // StallGuard capable drivers only
    #define X_STALL_SENSITIVITY  11
    #define X2_STALL_SENSITIVITY X_STALL_SENSITIVITY
    #define Y_STALL_SENSITIVITY  10
    #define Y2_STALL_SENSITIVITY Y_STALL_SENSITIVITY

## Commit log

2019-07-20 init commit
    [Configuration.h, Configuration_adv.h]
2019-07-21 add x y offsets
    [Configuration.h]
2019-07-21 reverse LCD encoder direction, CW is now up/+
    [Configuration.h]
2019-07-21 enable LCD buzzer
    [Configuration.h]
2019-07-24 shift x,y min positions
    [Configuration.h]
2019-07-26 change LCD info style to Prusa
    [Configuration.h]
2019-07-26 move to common folder
    [Configuration.h, Configuration_adv.h]
2019-07-27 create seperate directory for 3D Touch probe
    [Configuration.h, Configuration_adv.h, Tronxy_P802M_3DTouch_Mount.FCStd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]
2019-07-27 probe boundry adjustments
    [Configuration.h]
2019-07-28 disable bed PID, causing thermal runaway
    [Configuration.h]
2019-07-31 reduce false thermal runaway
    [Configuration.h, Configuration_adv.h]
2019-08-31 PID adjustments
    [Configuration.h]
2019-08-31 increase thermal runawy bed settings to lower false positives
    [Configuration_adv.h]
2019-10-06 enable babystepping
    [Configuration_adv.h]
2019-10-06 update marlin
    [Configuration.h, Configuration_adv.h]
2019-12-15 update marlin to 2.0.0 release
    [Configuration.h, Configuration_adv.h]
2020-06-09 Create Nema 17 28mm.step
    [Nema 17 28mm.step]
2020-06-09 Create Nema 17 40mm.step
    [Nema 17 40mm.step]
2020-06-09 mirror z motor mount
    [AM8-pbear.FCStd, z_motor_mount_left.step]
2020-06-09 Create z motor mount left.stl
    [z motor mount left.stl]
2020-06-09 rename with dashes
    [z_motor_mount_left.stl]
2020-06-10 add left z stabalizer
    [AM8-pbear.FCStd, z_stabalizer_left.step]
2020-06-10 fix chamfers
    [AM8-pbear.FCStd, z_stabalizer_left.step]
2020-06-11 add bear extruder x axis
2020-06-11 fix side bolt depth
    [z_stabalizer_left.step, z_stabalizer_left.stl]
2020-06-11 move to step dir
    [AM8.step, z_motor_mount_left.step, z_stabalizer_left.step]
2020-06-11 add y axis parts
    [Y_idler_bottom_Bear_RHD.stp, Y_idler_holder_Bear_RHD.stp, y_idler.step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]
2020-06-12 spell check
    [z_stabilizer_left.stl, z_stabilizer_right.stl]
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2020-06-12 add y motor mount
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2020-06-13 y belt holder teeth in correct direction
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2020-06-14 add unmodified stl files
    [2_Bottom_Tee_Plate.stl, 2_Top_Corner_Plate.stl, 4_Bottom_Corner_Plate.stl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]
2020-06-16 add unmodified files from prusa bear upgrade
    [cable_guide_back_a.stl, cable_guide_back_b.stl, extruder_cover.stl]
2020-06-19 add universal BTT enclosure
    [Anchor_SKR_Bear_Long_modified.step, Bear_MK3_Body_modified.step, Bear_Mk3_Cover.step]
2020-07-02 create mount for bottom of btt skr enclosure
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2020-07-08 remove wrong power supply
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2020-07-10 add psu bracket stl
    [psu_bracket.stl]
2020-07-10 add psu cover
    [psu_cover.stl]
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2020-07-11 flated top of hole on bl touch fan bracket
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2020-07-11 add marlin
    [Configuration.h, Configuration_adv.h]
2020-07-12 add extruder mount
    [extruder_mount.stl]
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2020-07-18 modify config
    [Configuration.h, Configuration_adv.h]
2020-07-19 update config
    [Configuration.h, Configuration_adv.h]
2020-07-20 nozzle park on sd stop
    [Configuration_adv.h]
2020-07-21 unmodify x idler, shorten x rods
2020-07-21 unmodifed x idler, shorten x rods
2020-07-21 more settings
    [Configuration.h, Configuration_adv.h]
2020-07-23 increase max extrude
    [Configuration.h]
2020-07-23 default lin k set to 0
    [Configuration_adv.h]
2020-07-27 switch to pinda probe from bltouch
    [Configuration.h]
2020-08-01 new marlin version
    [Configuration.h, Configuration_adv.h]
2020-08-01 modify config files for Tronxy AM8
    [Configuration.h, Configuration_adv.h]
2020-08-01 enable lcd info menu
    [Configuration_adv.h]
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2020-08-23 extruder fan auto on above 50C
    [Configuration_adv.h]
2020-08-24 lower homing speed
    [Configuration.h]
2020-12-11 change temp sensor, E0 driver
    [Configuration.h]
2020-12-11 update to Marlin 2.0.7.2
    [Configuration.h, Configuration_adv.h]
2020-12-11 goto z=10 after homing
    [Configuration.h]
2020-12-12 invert extruder direction
    [Configuration.h]
2023-12-26 fix mangled sketch on left z motor mount
2023-12-26 increase zrod stabilizer hole diameter
    [z_stabilizer_left.stl, z_stabilizer_right.stl]
2023-12-26 start upgrade to new Marlin version
    [Configuration.h, Configuration_adv.h, esp32.csv]
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2024-01-05 enable sfs V2 filament sensor
    [Configuration.h]
2024-01-05 use A4988 as extruder driver
    [Configuration.h]
2024-01-06 homing bump set to zeros
    [Configuration_adv.h]
2024-01-06 enable hotend fan
    [Configuration_adv.h]
2024-01-06 create filament sensor mount
    [sfs_v2-mount.stl, sfs_v2.FCStd]
2024-01-07 disable filament encoder sensor, use simple switch sensor on x+
    [Configuration.h]
2024-01-07 more speed
    [Configuration.h]
2024-01-07 no lcd backlight pin, disable timeout
    [Configuration_adv.h]
2024-01-07 set z probe offset
    [Configuration.h]
2024-01-07 slow xy feedrate during z probes
    [Configuration.h]
2024-01-07 speed up z feedrate during z probe
    [Configuration.h]
2024-01-07 adjust bed temp thermal protection settings
    [Configuration_adv.h]
2024-01-08 longer wire support
    [bed_standoff_wire_strain_relief.stl, heated_bed_mount.FCStd]
2024-03-16 slow down!
    [Configuration.h]
2024-03-16 slower probe speed, nozzle park front right
    [Configuration.h]
2024-03-16 slower probe
    [Configuration.h]
2024-03-17 slow down park feedrate
    [Configuration.h]
2024-03-23 increase max temp, dont confirm print file on select
    [Configuration.h, Configuration_adv.h]
2024-11-22 new marlin
    [Configuration.h, Configuration_adv.h, esp32.csv]

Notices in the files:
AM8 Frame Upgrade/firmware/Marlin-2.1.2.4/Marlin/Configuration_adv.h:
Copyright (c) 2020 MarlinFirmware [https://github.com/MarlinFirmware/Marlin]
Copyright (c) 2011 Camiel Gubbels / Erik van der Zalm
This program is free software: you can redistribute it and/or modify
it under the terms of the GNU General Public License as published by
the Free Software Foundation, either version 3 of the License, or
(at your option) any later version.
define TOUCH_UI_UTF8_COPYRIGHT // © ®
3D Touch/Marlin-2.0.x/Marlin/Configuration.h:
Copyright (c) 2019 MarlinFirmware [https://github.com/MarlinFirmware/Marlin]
